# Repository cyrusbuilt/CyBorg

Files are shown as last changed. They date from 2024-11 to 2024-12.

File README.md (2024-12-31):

# CyBorg
ATX-compliant Z80-based SBC motherboard

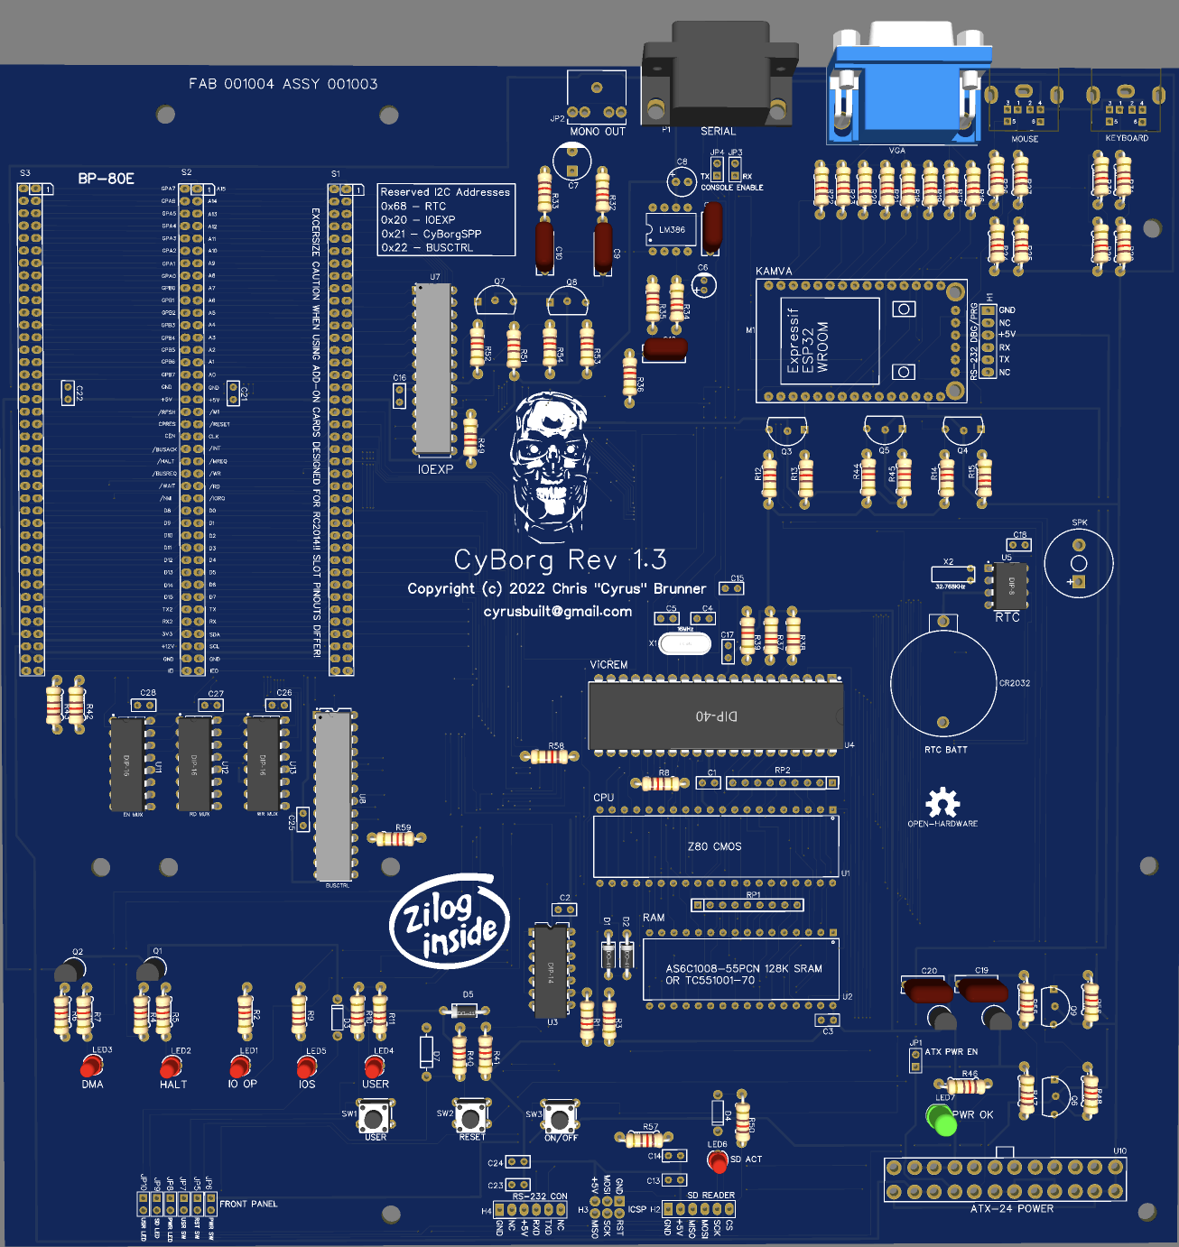
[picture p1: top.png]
CyBorg


## DISCLAIMER
This board is very much in the alpa stages and subject to design changes. This is my first SBC design and I'm learning as I go. As such this board is certainly not intended for production purposes.

## Synopsis
Being a huge fan of the retro-computing scene, and having built a few different "modern retro" computers from kits that were Z80 and Z180-based, I decided to study their schematics and try to design one myself. The design I settled on is a kind of amalgamation of the [Z80-MBC2](https://github.com/SuperFabius/Z80-MBC2) and my [CyrUX Board](https://github.com/cyrusbuilt/CyrUX) and a variation of the [RC2014 Enhanced Bus](https://smallcomputercentral.com/documentation/specification-rc2014-bus/#enhanced). CyBorg represents my first attempt at a CP/M and [Fuzix](https://github.com/EtchedPixels/FUZIX)-compatible retro computer that you can mount in a standard PC chassis.

## Features
- VGA Display (1280x768 B&W, 1024x720 4 color, 800x600 8 color, 720x520 16 color, 640x480 16 color @ 73Hz, 640x480 16 color @ 60Hz, 640x350 16 color, 512x384 64 color, and 400x300 64 color)
- PS/2 Keyboard and Mouse
- Serial Console
- Amplified Mono Audio
- Battery-backed Hardware Real-Time Clock
- Z80 CPU @ 8MHz
- 128K SRAM
- ATX 2.01-compliant
- Header for microSD card reader
- Front Panel Headers
- BP-80E Expansion Slots x3
- iLoad Intel-HEX loader firmware embedded.
- Optionally boots CP/M 2.2, CP/M 3, QP/M 2.71, Forth, BASIC, and Fuzix.

## Feature Break-Down
The features on this board are implemented using what I call "ViCREM" (formerly "Northbridge") and "KAMVA" (formerly "SouthBridge"). Both chips are responsible for different areas of the board. The Southbridge operates identically to my CyrUX board, but with ATX power management and boot sequence control added to it. The following is a breakdown of what each is and does:

## ViCREM (formerly 'Northbridge')
1) Atmel ATMEGA32A-PU
2) Specs:
	* 8-bit MCU @ 16MHz
	* 40-pin DIP package
	* 32KB Flash
	* 8KB EEPROM
	* 16KB RAM
3) Responsibilities:
	* Choreograph data between CPU, RAM, and data bus.
	* Control and provide interface for RTC (DS1307).
	* Control and provide interface for I/O expansion (via MCP23017).
	* Control onboard buzzer/speaker.
	* Communicate with Southbridge.
	* Expose OpCodes for system programming.
	* Provides system clock (4/8MHz).
	* Provides system ROM and bootstrapping.
	* RS-232 UART.

## KAMVA (formerly 'Southbridge')
1) [Adafruit Huzzah ESP32](https://www.adafruit.com/product/4172)
2) Specs:
	* 32bit dual-core Tensilica LX6 MCU @ 240MHz.
	* 520KB SRAM.
	* 802.11b/g/n HT40 Wi-Fi.
	* Dual-mode Bluetooth (classic and BLE).
	* 4MB Flash
	* PCB antenna
3) Responsibilities:
	* ATX Power management.
	* Boot sequence control.
	* [FabGL-based](https://github.com/fdivitto/FabGL) Terminal System which provides:
	* PS/2 Keyboard and Mouse input.
	* Amplified Mono Audio Output (LM386).
	* VGA Display Output.
	* Possible future networking support.

## Core
1) Zilog Z80 CMOS CPU @ 8MHz
	* Main System Processor.
2) AS6C1008-55PCN 128KB SRAM (banked 64K x 2)
	* Main System RAM.

## Expansion Bus Slots
The expansion bus slots are an unofficial variation of the RC2014 Enhanced bus I call "BP-80E" or "BP-80 Enhanced" which is kind of a misnomer given the actual pinout of the unofficial BP-80 bus definition, but seemed appropriate for my purposes (at least until I come up with a better name for it). It is pin-compatible with the RC2014 Standard and Enhanced bus slots and therefore should be compatible with existing add-on boards, but adds the following changes:
1) Pins 41 - 56 map to the I/O pins on the MCP23017 I/O expander and therefore gives us 16 shared GPIO pins (3.3V).
2) Pins 39 and 79 are additional GND.
3) Pin 78 is +12V.
4) Pin 77 is +3.3V.
5) Pins 37 and 38 are I2C SDA & SCL (respectively).
6) Pin 60 is Card Presence indicator
7) Pin 61 is Card Enable
8) /IORQ, /WR, and /RD signals are all unique to each slot.

## Jumpers and Headers
1) Header H4: RS-232 Serial from the Northbridge/Main system. This is also tied to the DB-9 Serial port next to the VGA connector.
2) Header H3: ICSP header used to program/debug the Northbridge.
3) Header H2: This is essentially an SPI bus header used to attach the SD Card Reader.
4) Header H1: RS-232 serial header that goes directly to the Southbridge and used to program/debug the Southbridge. Intended to be used with a USB-to-Serial FTDI cable.
5) Jumper JP1: (should be jumpered for normal operation) enables power to the Southbridge via the 5VSB line from the ATX power supply. Unjumper this to enable power from the FTDI cable.
6) Jumpers JP3 and JP4: (should be jumpered for normal operation) enables the Serial connection to the Southbridge.
7) JP5: Front-panel reset switch. Momentarily short to reset the system. Same as pressing RESET button.
8) JP6: Front-panel power button. Momentarily short to power system on. Short for >= 10s to power off. Same as pressing ON/OFF button.
9) JP7: Front-panel USER button. Press and hold during power on to get boot mode selection menu. Same as pressing USER button.
10) JP8: Front-panel power LED header. Same as PWR OK LED.
11) JP9: Front-panel SD card activity LED. Same as SD ACT LED.
12) JP10: Front-panel boot mode LED. Same as USER LED.

## Boot Sequence
Being an ATX-compliant board, this system uses an ATX-24 power connector intended to be used with an ATX Power Supply. The ATX power management and boot sequence works as follows: KAMVA receives it's power from the 5VSB line, which is always on as long as the ATX power supply has power (but not necessarily "running"). On power-on KAMVA enters boot stage 0, which *only* initializes the debug port and the ATX power management system, then waits for the user to press the power button.

When the user presses and releases the power button, it then drives the ATX PC_ON line LOW to turn on the ATX supply and waits for the PWR_OK line to go HIGH (as indicated by the PWR OK LED). When the PWR_OK signal is received, the Southbridge enters boot stage 1, which initializes the VGA display, PS/2 keyboard and mouse, and audio, followed by boot stage 2 which signals ViCREM to boot. At the same time ViCREM should have received power via the +5V line and entered boot stage 0, which initializes the RS-232 serial (and debug) interface and waits for the RUN signal line to go HIGH. The last step of KAMVA's boot stage 2 should drive the RUN_3V3 line high and wait (5s timeout) for ViCREM to complete bootstage 1 and start receiving serial data. When ViCREM sees the RUN signal it should enter boot stage 1 which should first announce it's firmware version to the serial port then configure the WAIT and WAIT_RES lines then check the USER button for boot mode selection. Once KAMVA sees serial data, it has completed it's own boot sequence and will continuously poll the power button for presses. If the user presses and holds the power button for >= 10s, then KAMVA will force-power down by driving the PC_ON line HIGH which will immediately drop out power from the power supply forcing the rest of the system off. KAMVA will then do a soft-reboot to re-init back to boot stage 0.

Back to ViCREM, after checking for boot mode selection and storing the flag, it enters boot stage 2 which initializes all the appropriate address and data lines on the system bus, then the logical RAM banks, system clock, and console lines, then moves to boot stage 3. Stage 3 reads the CPU speed mode, boot selection, and CP/M auto-exec flags from EEPROM, initializes the I2C interface and scans for the I/O expander, RTC, BUSCTLR and IOEXP chips, and CyBorgSPP interface then outputs boot info to serial, then moves to boot stage 4. Stage 4 tries to mount the SD card (if present) and presents the user with boot mode selection menu if the USER line was LOW at boot and then proceeds to load the selected (via menu or from EEPROM or fallback to default) boot image into RAM (either from flash or from SD card), then moves to boot stage 5. Stage 5 holds the CPU in RESET, then initializes the system clock, then flushes the serial buffer, then releases the RESET line so the CPU begins executing.

Additional detail can be found in the firware projects for [ViCREM](https://github.com/cyrusbuilt/CyBorg-Northbridge) and [KAMVA](https://github.com/cyrusbuilt/CyBorg-Southbridge).

## Project Structure
All design files are in the "schematics" folder. It contains the JSON exports for the [EasyEDA](https://easyeda.com/) schematic and PCB CAD files, the BOM in CSV format, PDFs of the schematic and PCB designs, and then in schematics/gerber are the production gerber files.

## I want one!
I have no plans to make CyBorg into a commercial product nor do I intend to sell kits. So if you want to build one, you'll need to take the gerber files and have the PCB made, then order the parts listed in the BOM and assemble it yourself. You'll need to be familiar with soldering through-hole components (I recommend an adjustable temperature soldering iron) and at least a multimeter (I often use a logic probe too)) and some wire snips to cut the legs on things like resistors and capacitors to size after you solder them. **However**, at this time, I would hold off on building one until I've finalized the design.

## Cool! I built one! Now what?
You'll need an ATX power supply (you can even use a Pico PSU). The next thing you'll want to do is flash the KAMVA (formerly known as the "Southbridge") firmware. Go see the project for that [here](https://github.com/cyrusbuilt/CyBorg-Southbridge). After you've done that, you'll need to flash the ViCREM (formerly known as "Northbridge") firmware. Go see the project for that [here](https://github.com/cyrusbuilt/CyBorg-Northbridge).

## Possible Revision Changes
1) Add fan headers
2) Change expansion bus slots to different connector type.

## Sponsorship/Special Thanks
A big special thanks to [PCBWay](https://www.pcbway.com) for their sponsorship on this project! It can't be stated enough the quality of their boards and their service. I've been using PCBWay to produce my boards for years now and I've always been really impressed. Fast shipping, fast service, reasonable cost, and the quality has always been stellar. Their pre-production team has even caught mistakes I didn't notice before sending my designs in. The ordering process is simple: just upload a zip file of your gerbers (their site even renders a preview of what the board will look like!) and then you can tweak parameters if needed (including color) and quantity, pick your shipping method, and that's it! They've even produced a series of videos about the whole process you can view [here](https://www.pcbway.com/pcb-service.html?step=1#miao1).

Just look at this beauty! (I'm a huge fan of their black PCBs)
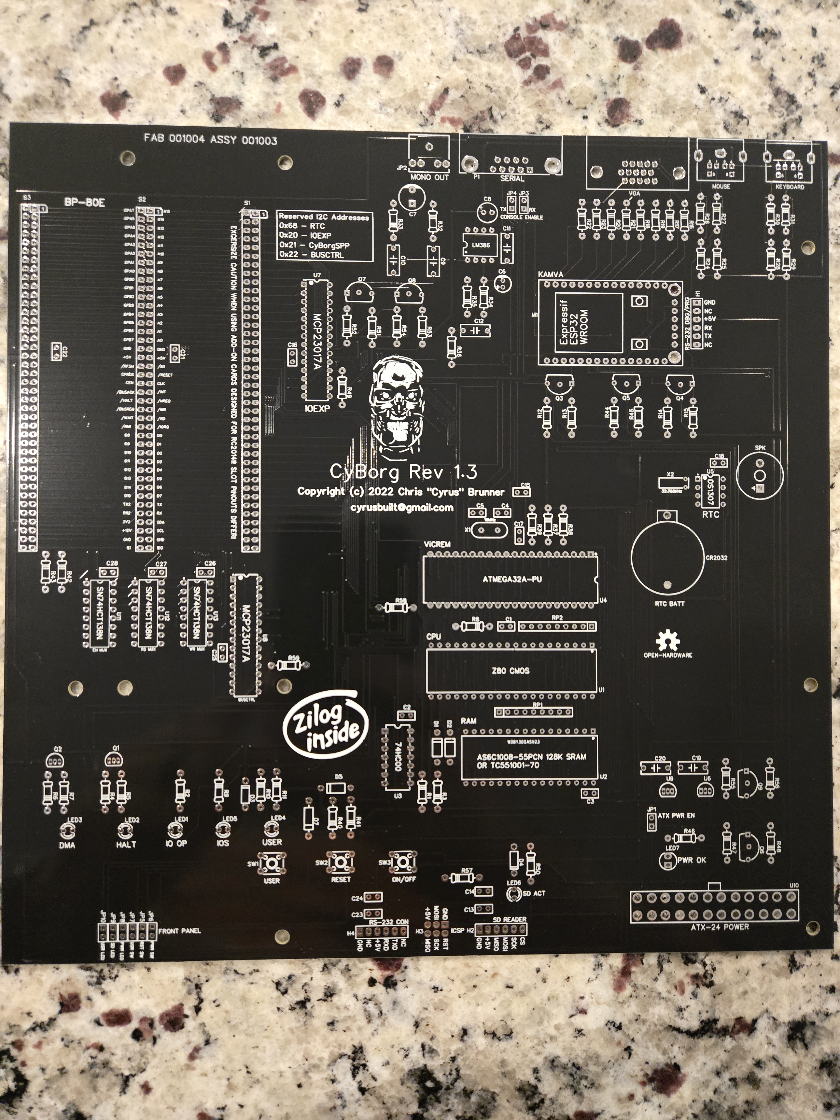
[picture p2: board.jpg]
CyBorg_Board


## Credits
- CyBorg's core is derived from the works of "Just4Fun" a.k.a "SuperFabius" ([https://github.com/SuperFabius](https://github.com/SuperFabius)) (parts of the hardware design and IOS firmware code).
- Southbridge firmware implements the FabGL library and is essentially a modified version of the AnsiTerminal example by Fabrizio Di Vittorio ([http://www.fabglib.org/index.html](http://www.fabglib.org/index.html))
- Northbridge firmware implements the PetitFS library by ChaN ([http://elm-chan.org/fsw/ff/00index_p.html](http://elm-chan.org/fsw/ff/00index_p.html))
- Southbridge firmware implements the ButtonEvent library by Renato Ferriera ([https://github.com/renatoferreirarenatoferreira/ebl-arduino/tree/master/ButtonEvent](https://github.com/renatoferreirarenatoferreira/ebl-arduino/tree/master/ButtonEvent))
- ViCREM (Northbridge) firmware uses [MightyCore](https://github.com/MCUdude/MightyCore) bootloader by [MCUDude](https://github.com/MCUdude)

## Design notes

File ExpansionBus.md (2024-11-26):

# BP-80E Expansion Bus

CyBorg uses a custom Expansion Bus used for add-on cards called "BP-80 Enhanced" (aka. "BP-80E"). This bus specification is essentially a variation of the [Official RC2014 Enhanced Bus Specification](https://smallcomputercentral.com/documentation/specification-rc2014-bus/#enhanced) with the following changes:

1) Row 2 Pins 41 - 56 are used by the 16 GPIOS provided by the MCP23017 I/O expander chip located next to the first bus connector (these pins were orginally unused).
2) Row 1 and Row 2 pins 37 - 40 were originally specified for USER functions (which could be anything), which I've assigned to extra grounds, power pins with additional voltages (+3.3V and +12V) and interrupt cascade.
3) Row 2 Pins 60 & 61 are used for Card Presence and Card Enable (respectively).

With the exception of the above pin assignment changes, all other pin definitions remain the same and as such, *should be* compatible with official [RC2014](https://rc2014.co.uk/) add-on cards and cards designated as being "Designed for RC2014" with the caveat of any card that specifically uses any of the above pins for other purposes would, of course, not be compatible and could therefore potentially cause damage to both this board and any board you plug into intended for use in RC2014-compatible systems. **USE WITH CAUTION**.

# LEGAL DISCLAIMER
I am not liable for any damage to any device you interface with this board, particularly if you ignore the above information. While I did adopt a *similar* expansion bus, they are NOT the same and should not be treated as such. This board should not be considered to be a RC2014-compatible system. They are fundamentally different! I only offer the above info because I have indeed tested at least one add-on board designated as being "Designed for RC2014" without issue, but you should excersize caution and if you don't know for sure, don't try it!

# Expansion Bus Pinout

The following table describes the pin definitions:

| Row  | Pin # | Signal | Description |
| :--- | :---  | :--- | :--- |
| 1 (R)| 1 | A15 | Address bit 15 |
| 1 (R)| 2 | A14 | Address bit 14 |
| 1 (R)| 3 | A13 | Address bit 13 |
| 1 (R)| 4 | A12 | Address bit 12 |
| 1 (R)| 5 | A11 | Address bit 11 |
| 1 (R)| 6 | A10 | Address bit 10 |
| 1 (R)| 7 | A9 | Address bit 9 |
| 1 (R)| 8 | A8 | Address bit 8 |
| 1 (R)| 9 | A7 | Address bit 7 |
| 1 (R)| 10 | A6 | Address bit 6 |
| 1 (R)| 11 | A5 | Address bit 5 |
| 1 (R)| 12 | A4 | Address bit 4 |
| 1 (R)| 13 | A3 | Address bit 3 |
| 1 (R)| 14 | A2 | Address bit 2 |
| 1 (R)| 15 | A1 | Address bit 1 |
| 1 (R)| 16 | A0 | Address bit 0 |
| 1 (R)| 17 | GND | Ground |
| 1 (R)| 18 | +5V | +5V DC |
| 1 (R)| 19 | /M1 | Opcode fetch cycle |
| 1 (R)| 20 | /RESET | Northbridge/CPU reset |
| 1 (R)| 21 | CLK | CPU Clock |
| 1 (R)| 22 | /INT | Maskable Interrupt |
| 1 (R)| 23 | /MREQ  | Memory Request |
| 1 (R)| 24 | /WR | Write data**** |
| 1 (R)| 25 | /RD | Read data**** |
| 1 (R)| 26 | /IORQ  | I/O Request**** |
| 1 (R)| 27 | D0 | Data bit 0 |
| 1 (R)| 28 | D1 | Data bit 1 |
| 1 (R)| 29 | D2 | Data bit 2 |
| 1 (R)| 30 | D3 | Data bit 3 |
| 1 (R)| 31 | D4 | Data bit 4 |
| 1 (R)| 32 | D5 | Data bit 5 |
| 1 (R)| 33 | D6 | Data bit 6 |
| 1 (R)| 34 | D7 | Data bit 7 |
| 1 (R)| 35 | TX | Serial Transmit (UART) |
| 1 (R)| 36 | RX | Serial Recieve (UART) |
| 1 (R)| 37 | SDA | I2C Serial Data |
| 1 (R)| 38 | SCL | I2C Serial Clock |
| 1 (R)| 39 | GND | Ground |
| 1 (R)| 40 | IEO | Interrupt cascade (out) |
| 2 (L)| 41 | GPA7 | IOEX Port A bit 7* |
| 2 (L)| 42 | GPA6 | IOEX Port A bit 6* |
| 2 (L)| 43 | GPA5 | IOEX Port A bit 5* |
| 2 (L)| 44 | GPA4 | IOEX Port A bit 4* |
| 2 (L)| 45 | GPA3 | IOEX Port A bit 3* |
| 2 (L)| 46 | GPA2 | IOEX Port A bit 2* |
| 2 (L)| 47 | GPA1 | IOEX Port A bit 1* |
| 2 (L)| 48 | GPA0 | IOEX Port A bit 0* |
| 2 (L)| 49 | GPB0 | IOEX Port B bit 0* |
| 2 (L)| 50 | GPB1 | IOEX Port B bit 1* |
| 2 (L)| 51 | GPB2 | IOEX Port B bit 2* |
| 2 (L)| 52 | GPB3 | IOEX Port B bit 3* |
| 2 (L)| 53 | GPB4 | IOEX Port B bit 4* |
| 2 (L)| 54 | GPB5 | IOEX Port B bit 5* |
| 2 (L)| 55 | GPB6 | IOEX Port B bit 6* |
| 2 (L)| 56 | GPB7 | IOEX Port B bit 7* |
| 2 (L)| 57 | GND | Ground |
| 2 (L)| 58 | +5V | +5V DC |
| 2 (L)| 59 | /RFSH  | Refresh |
| 2 (L)| 60 | CPRES  | Card Presence indicator* |
| 2 (L)| 61 | CEN | Card Enable* |
| 2 (L)| 62 | /BUSACK| Bus acknowledge |
| 2 (L)| 63 | /HALT  | Halt/pause execution |
| 2 (L)| 64 | /BUSREQ| Bus request |
| 2 (L)| 65 | /WAIT  | Enter wait state |
| 2 (L)| 66 | /NMI | Non-Maskable Interrupt |
| 2 (L)| 67 | D8 | Data bit 8** |
| 2 (L)| 68 | D9 | Data bit 9** |
| 2 (L)| 69 | D10 | Data bit 10** |
| 2 (L)| 70 | D11 | Data bit 11** |
| 2 (L)| 71 | D12 | Data bit 12** |
| 2 (L)| 72 | D13 | Data bit 13** |
| 2 (L)| 73 | D14 | Data bit 14** |
| 2 (L)| 74 | D15 | Data bit 15** |
| 2 (L)| 75 | TX2 | Serial Transmit 2*** |
| 2 (L)| 76 | RX2 | Serial Receive 2*** |
| 2 (L)| 77 | 3V3 | +3.3V DC |
| 2 (L)| 78 | +12V | +12V DC |
| 2 (L)| 79 | GND | Ground |
| 2 (L)| 80 | IEI | Interrupt cascade (in) |

\* - Denotes signal level is 3.3V. All other signals are at a 5V level.

\** - Denotes data bus signal is present on expansion bus *ONLY* and does not connect to the CPU's data bus.

\*** - Denotes serial signals present on the expansion bus *ONLY* and does not connect to any UART present on  ViCREM or KAMVA.

\**** - Denotes signal is unique to the slot, meaning: it's individually controlled by the associated
mux chip for each signal and assigned to the specific slot.

\/ - Signal prefix denotes a signal that is active low.

See the [Z80 CPU User Manual](https://www.zilog.com/docs/z80/um0080.pdf) for documentation on the Z80-specific signals above.

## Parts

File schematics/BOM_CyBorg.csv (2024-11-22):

ID | Name | Designator | Footprint | Quantity | Manufacturer Part | Manufacturer | Supplier | Supplier Part | Price
1 | 100nF | C1,C2,C3,C16,C21,C22,C25,C26,C27,C28 | CAP-RAD-2.54MM | 10
2 | 22pF | C4,C5 | CAP-RAD-2.54MM | 2
3 | 10uF | C6 | ELECTROLYTIC CAPACITOR | 1 | electrolytic capacitor 10UF 50V high frequency | ValuePro | LCSC | C78759 | 0.014
4 | 220uF | C7 | 220UF ELECTROLYTIC | 1 | Aluminum electrolytic capacitors47uF 63V 20% High frequency green gold | ValuePro |  | C60712 | 0.023
5 | 100uF | C8 | ELECTROLYTIC CAPACITOR 100UF | 1
6 | 47nF | C9 | CAP-TH_L8.8-W3.6-P7.30-D0.5 | 1 | 0.1uF/250V | null | LCSC | C9900015263
7 | 2.2nF | C10 | CAP-TH_L8.8-W3.6-P7.30-D0.5 | 1 | 0.1uF/250V | null | LCSC | C9900015263
8 | 100nF | C11 | CAP-TH_L8.8-W3.6-P7.30-D0.5 | 1 | 0.1uF/250V | null | LCSC | C9900015263
9 | 0.1uF | C12 | CAP-TH_L8.8-W3.6-P7.30-D0.5 | 1 | 0.1uF/250V | null | LCSC | C9900015263
10 | 0.1uF | C13,C15,C17,C18,C23 | CAP-RAD-2.54MM | 5
11 | 100uF | C14,C24 | CAP-RAD-2.54MM | 2
12 | 1nF | C19,C20 | CAP-TH_L8.8-W3.6-P7.30-D0.5 | 2 | 0.1uF/250V | null | LCSC | C9900015263
13 | BATT-CR2032 | CR2032 | BATT-CR2032 | 1
14 | 1N5817_C698892 | D1,D2,D5 | DO-41_BD2.4-L4.7-P8.70-D0.9-RD | 3 | 1N5817 | YANGJIE(扬杰) | LCSC | C698892 | 0.036
15 | 1N4148 | D3,D4 | 1N4148 | 2
16 | DIODE | D7 | DIODE-1N4001 | 1
17 | RS-232 | H1,H4 | HEADER-1X6-2.54MM | 2
18 | SD_READER | H2 | HEADER-1X6-2.54MM | 1
19 | ICSP | H3 | ICSP - 1 | 1
20 | ATX_PWR_EN | JP1 | HDR1X2 | 1
21 | AUDIO-JACK PTH | JP2 | AUDIO-JACK | 1
22 | RX_CON_EN | JP3 | HDR1X2 | 1
23 | TX_CON_EN | JP4 | HDR1X2 | 1
24 | RESET HDR | JP5 | HDR1X2 | 1
25 | PWR_BTN_HDR | JP6 | HDR1X2 | 1
26 | USER HDR | JP7 | HDR1X2 | 1
27 | PWR_OK | JP8 | HDR1X2 | 1
28 | SD_ACT | JP9 | HDR1X2 | 1
29 | USER_IND | JP10 | HDR1X2 | 1
30 | PS/2 Connector | KEYBOARD,MOUSE | PS2_PORT | 2
31 | IO_OP | LED1 | LED-TH_BD3.0-P2.54-FD | 1 | 204-10SURD/S530-A3 | EVERLIGHT(亿光) | LCSC | C99772 | 0.027
32 | HALT | LED2 | LED-TH_BD3.0-P2.54-FD | 1 | 204-10SURD/S530-A3 | EVERLIGHT(亿光) | LCSC | C99772 | 0.027
33 | DMA | LED3 | LED-TH_BD3.0-P2.54-FD | 1 | 204-10SURD/S530-A3 | EVERLIGHT(亿光) | LCSC | C99772 | 0.027
34 | USER | LED4 | LED-TH_BD3.0-P2.54-FD | 1 | 204-10SURD/S530-A3 | EVERLIGHT(亿光) | LCSC | C99772 | 0.027
35 | IOS | LED5 | LED-TH_BD3.0-P2.54-FD | 1 | 204-10SURD/S530-A3 | EVERLIGHT(亿光) | LCSC | C99772 | 0.027
36 | SD_ACT | LED6 | LED-TH_BD3.0-P2.54-FD | 1 | 204-10SURD/S530-A3 | EVERLIGHT(亿光) | LCSC | C99772 | 0.027
37 | LED 5MM GREEN | LED7 | LED 5MM GREEN | 1
38 | LM386 | LM386 | LM386 | 1 | LM386N-1/NOPB | LM386N-1/NOPB | Digi-Key
39 | HUZZAH-ESP32 | M1 | HUZZAH-ESP32 | 1
40 | RS232 DB-9 | P1 | DB9-TH_DB9-H-F_C2888345 | 1 | RS232DB99pin90度母座 | null | LCSC | C9900003665
41 | 2N2907 | Q1,Q2 | TO-92-3_L5.1-W4.1-P1.27-L | 2 | 2N2907A | ST(先科) | LCSC | C118537 | 0.023
42 | 2N7000 | Q3,Q4,Q5,Q6,Q7,Q8,Q9 | 2N7000 TO-92 B | 7
43 | 10K | R1,R4,R6,R8 | PKG-0.25W RESISTOR | 4 | MCF 0.25W 150R | MULTICOMP | Element14 | 9339175
44 | 1K | R2 | PKG-0.25W RESISTOR | 1 | MCF 0.25W 1K | MULTICOMP | Element14 | 9339175
45 | 1K2 | R3 | PKG-0.25W RESISTOR | 1 | MCF 0.25W 150R | MULTICOMP | Element14 | 9339175
46 | 680 | R5,R9 | PKG-0.25W RESISTOR | 2 | MCF 0.25W 150R | MULTICOMP | Element14 | 9339175
47 | 1K | R7 | PKG-0.25W RESISTOR | 1 | MCF 0.25W 150R | MULTICOMP | Element14 | 9339175
48 | 390 | R10,R11,R18,R20,R22 | PKG-0.25W RESISTOR | 5 | MCF 0.25W 150R | MULTICOMP | Element14 | 9339175
49 | 10k | R12,R13,R14,R15,R33,R34,R37,R38,R39,R41,R44,R45,R47,R48,R51,R52,R53,R54,R55,R56,R57 | PKG-0.25W RESISTOR | 21 | MCF 0.25W 150R | MULTICOMP | Element14 | 9339175
50 | 220 | R16,R17,R46 | PKG-0.25W RESISTOR | 3 | MCF 0.25W 150R | MULTICOMP | Element14 | 9339175
51 | 820 | R19,R21,R23 | PKG-0.25W RESISTOR | 3 | MCF 0.25W 150R | MULTICOMP | Element14 | 9339175
52 | 2k | R24,R25,R28,R29 | PKG-0.25W RESISTOR | 4 | MCF 0.25W 150R | MULTICOMP | Element14 | 9339175
53 | 120 | R26,R27,R30,R31 | PKG-0.25W RESISTOR | 4 | MCF 0.25W 150R | MULTICOMP | Element14 | 9339175
54 | 10 | R32 | PKG-0.25W RESISTOR | 1 | MCF 0.25W 150R | MULTICOMP | Element14 | 9339175
55 | 150 | R35 | PKG-0.25W RESISTOR | 1 | MCF 0.25W 150R | MULTICOMP | Element14 | 9339175
56 | 270 | R36 | PKG-0.25W RESISTOR | 1 | MCF 0.25W 150R | MULTICOMP | Element14 | 9339175
57 | 1k | R40 | PKG-0.25W RESISTOR | 1 | MCF 0.25W 150R | MULTICOMP | Element14 | 9339175
58 | 4k7 | R42,R43,R49,R59 | PKG-0.25W RESISTOR | 4 | MCF 0.25W 150R | MULTICOMP | Element14 | 9339175
59 | 330 | R50 | PKG-0.25W RESISTOR | 1 | MCF 0.25W 330R | MULTICOMP | Element14 | 9339175
60 | 39 | R58 | PKG-0.25W RESISTOR | 1 | MCF 0.25W 330R | MULTICOMP | Element14 | 9339175
61 | Resistor SIL x8 | RP1,RP2 | SIL-9 | 2
62 | BP-80E Card Socket | S1,S2,S3 | RC2014-HDR-2X40-S-F-R-2.54MM | 3
63 | BUZZER Ekulit RMP-14SP | SPK | BUZZER-R14-2P-7.6PITCH | 1 |  | Ekulit |  | RMP-14SP
64 | USER | SW1 | KEY-TH_4P-L6.0-W6.0-P4.50-LS6.5 | 1 | K2-1102DP-E4SW-04 | 韩国韩荣 | LCSC | C136684 | 0.04
65 | RESET | SW2 | KEY-TH_4P-L6.0-W6.0-P4.50-LS6.5 | 1 | K2-1102DP-E4SW-04 | 韩国韩荣 | LCSC | C136684 | 0.04
66 | PWR_ON_OFF | SW3 | KEY-TH_4P-L6.0-W6.0-P4.50-LS6.5 | 1 | K2-1102DP-E4SW-04 | 韩国韩荣 | LCSC | C136684 | 0.04
67 | Z80 | U1 | DIP40 | 1 | Z84C0008PEG
68 | AS6C1008-55PCN | U2 | DIP32 | 1 | AS6C1008-55PCN
69 | 74HC00N | U3 | DIP-14_L19.0-W7.0-P2.54-LS7.6-BL | 1 | 74HC00N | HTC Korea TAEJIN Tech | LCSC | C596352 | 0.659
70 | ATMEGA32A-PU | U4 | DIP-40_L52.3-W13.9-P2.54-LS15.2-BL | 1 | ATMEGA32A-PU | MICROCHIP | LCSC | C12703 | 5.22
71 | DS1307N | U5 | DIP-8_L9.8-W6.6-P2.54-LS7.6-BL | 1 | DS1307N | HGSEMI | LCSC | C434596 | 0.406
72 | DS1233-5+ | U6,U9 | TO-92-3_L4.9-W3.7-P1.27-L | 2 | DS1233-10+ | Maxim Integrated | LCSC | C474045 | 1.24
73 | MCP23017-E/SP | U7,U8 | DIP-28_L35.0-W6.5-P2.54-LS7.6-BL | 2 | MCP23017-E/SP | Microchip Tech | LCSC | C647352 | 1.999
74 | FR_ATX24 | U10 | FR_ATX24 | 1 | ATX-24
75 | SN74HCT138N | U11,U12,U13 | DIP-16_L19.2-W6.6-P2.54-LS7.6-BL | 3 | SN74HCT138N | TI(德州仪器) | LCSC | C67461 | 0.515
76 | VGA-001 | VGA | D-SUB-TH_VGA-002 | 1 | VGA-002 | BOOMELE(博穆精密) | LCSC | C138387 | 0.21
77 | 16MHz | X1 | OSC-TH_L10.0-W4.5-P5.00 | 1 | X49SD16MSD2SC | YXC(扬兴晶振) | LCSC | C16212 | 0.083
78 | Xtal 32.768KHz | X2 | XTAL 32.768KHZ | 1

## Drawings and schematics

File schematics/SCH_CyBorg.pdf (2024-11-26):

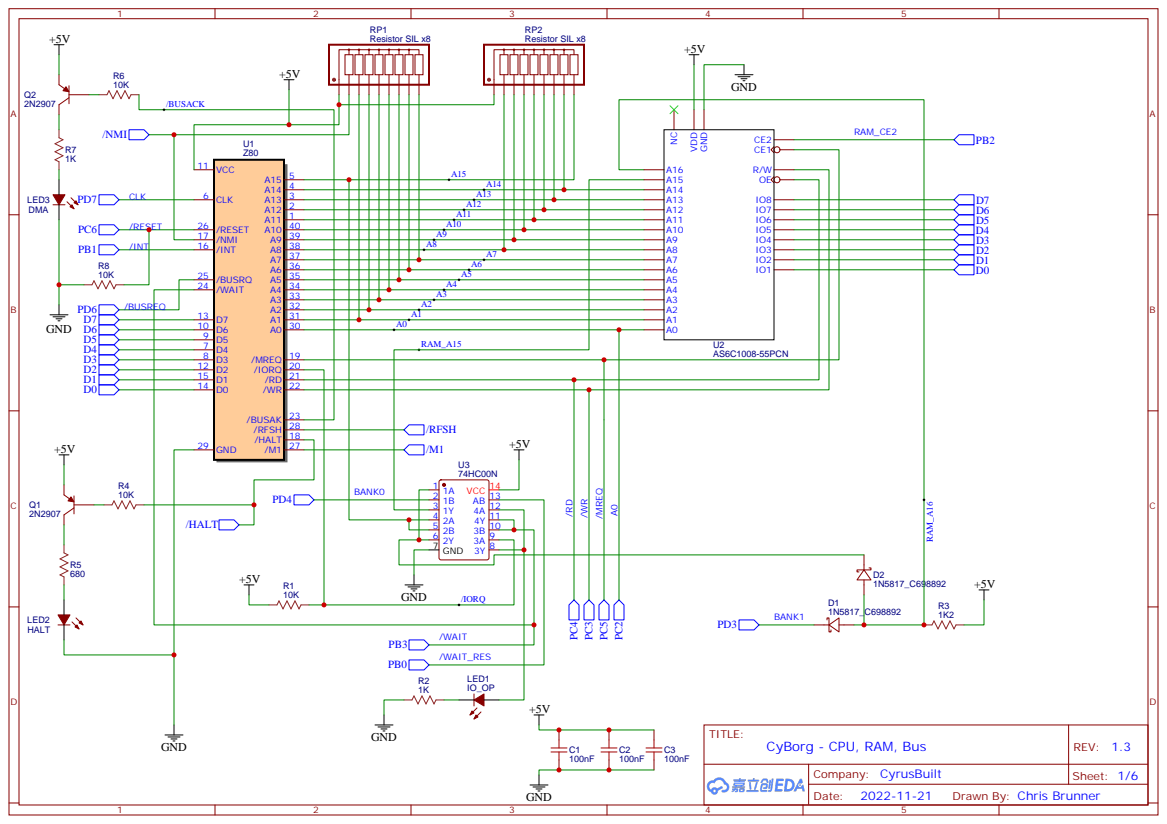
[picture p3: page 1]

Drawn By: Chris Brunner

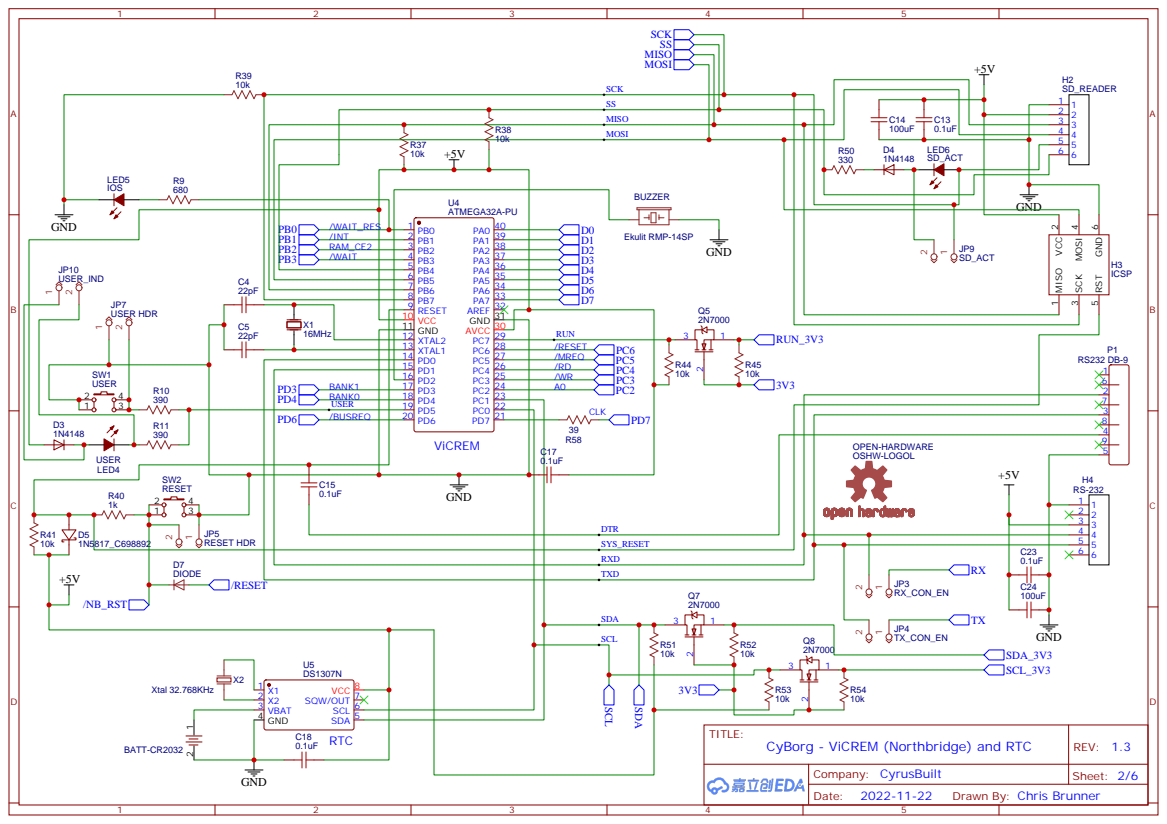
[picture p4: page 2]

MISO
MOSI

## MCU & SERIAL COMM. SECTION

## KAMVA

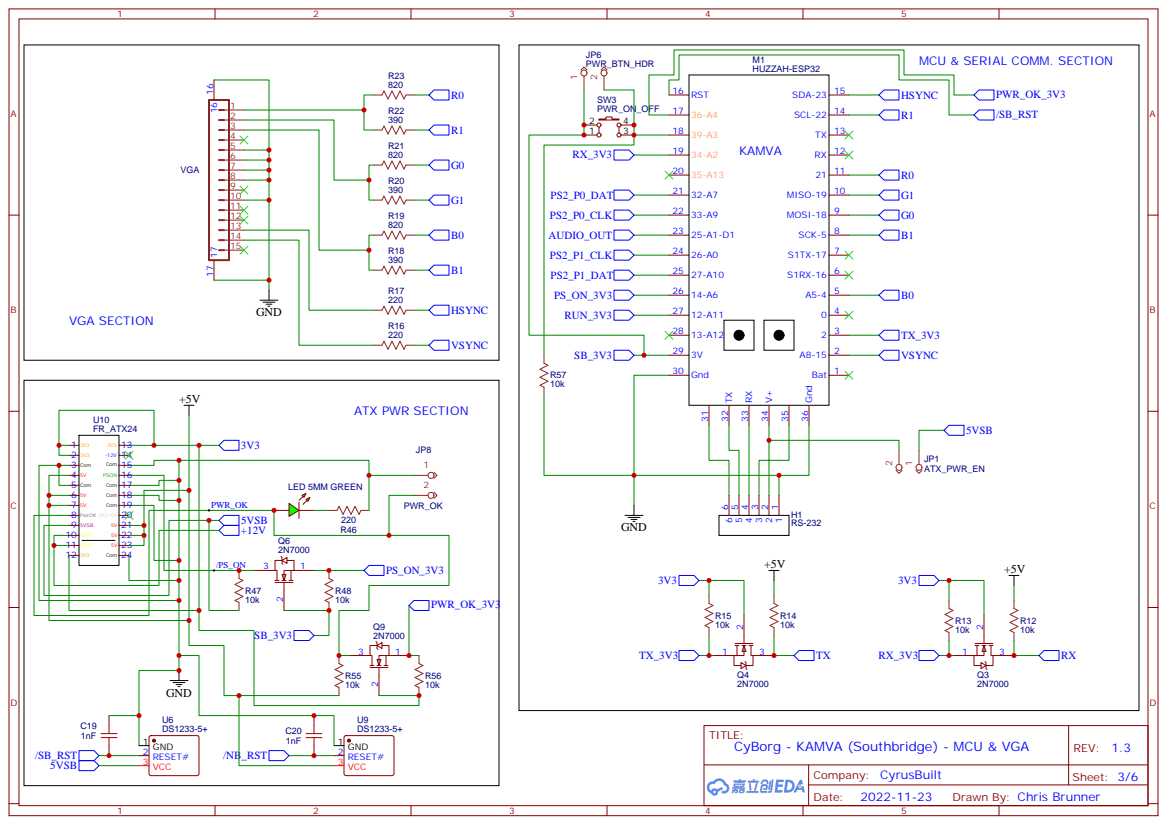
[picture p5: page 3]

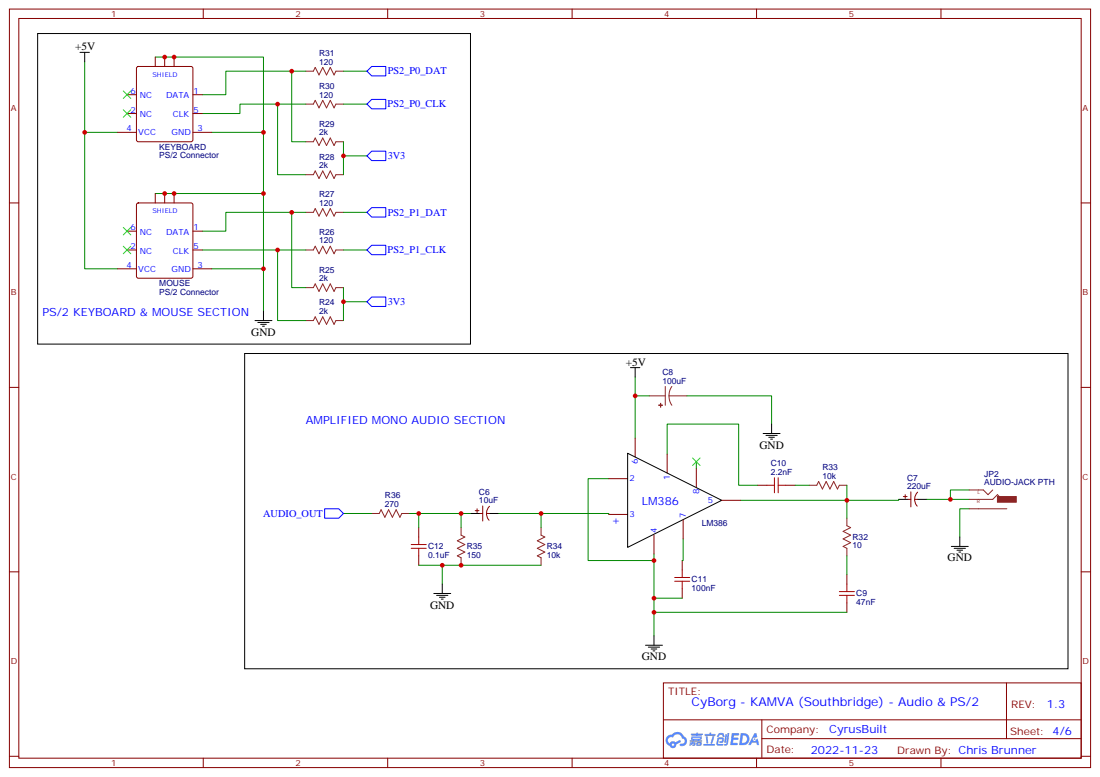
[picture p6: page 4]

AMPLIFIED MONO AUDIO SECTION

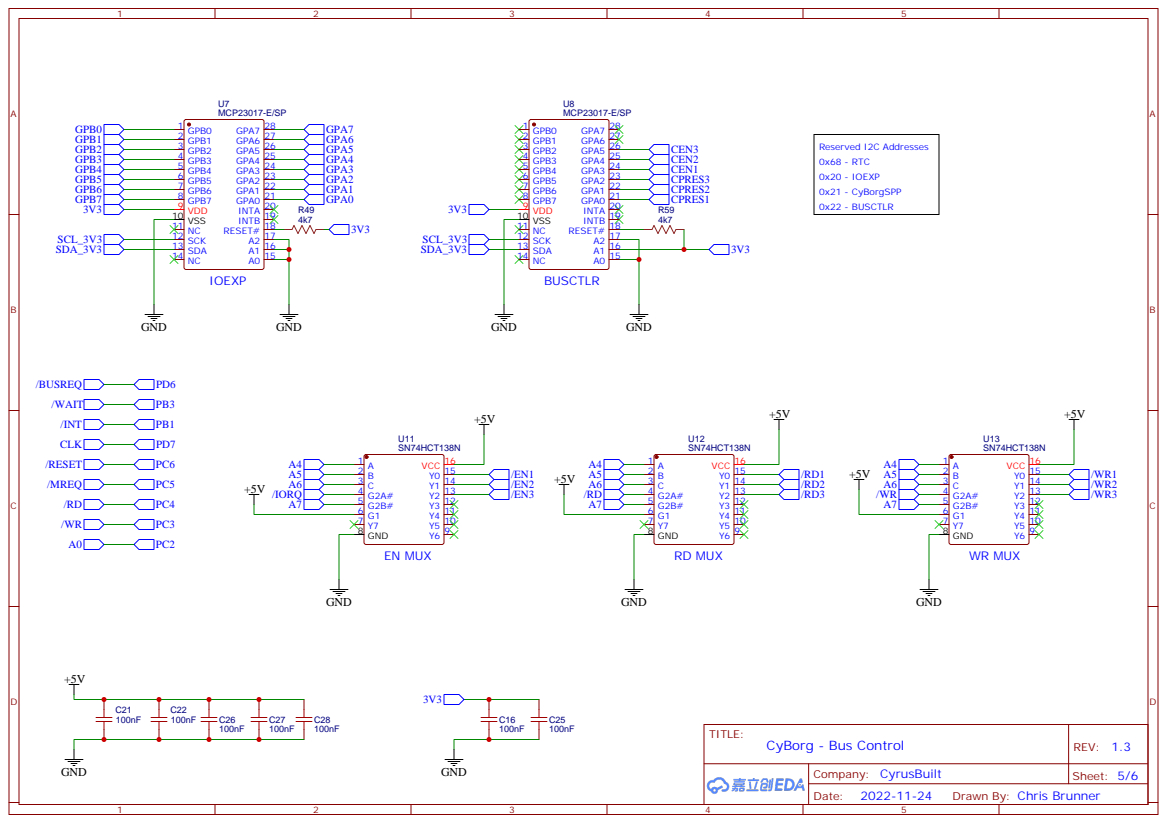
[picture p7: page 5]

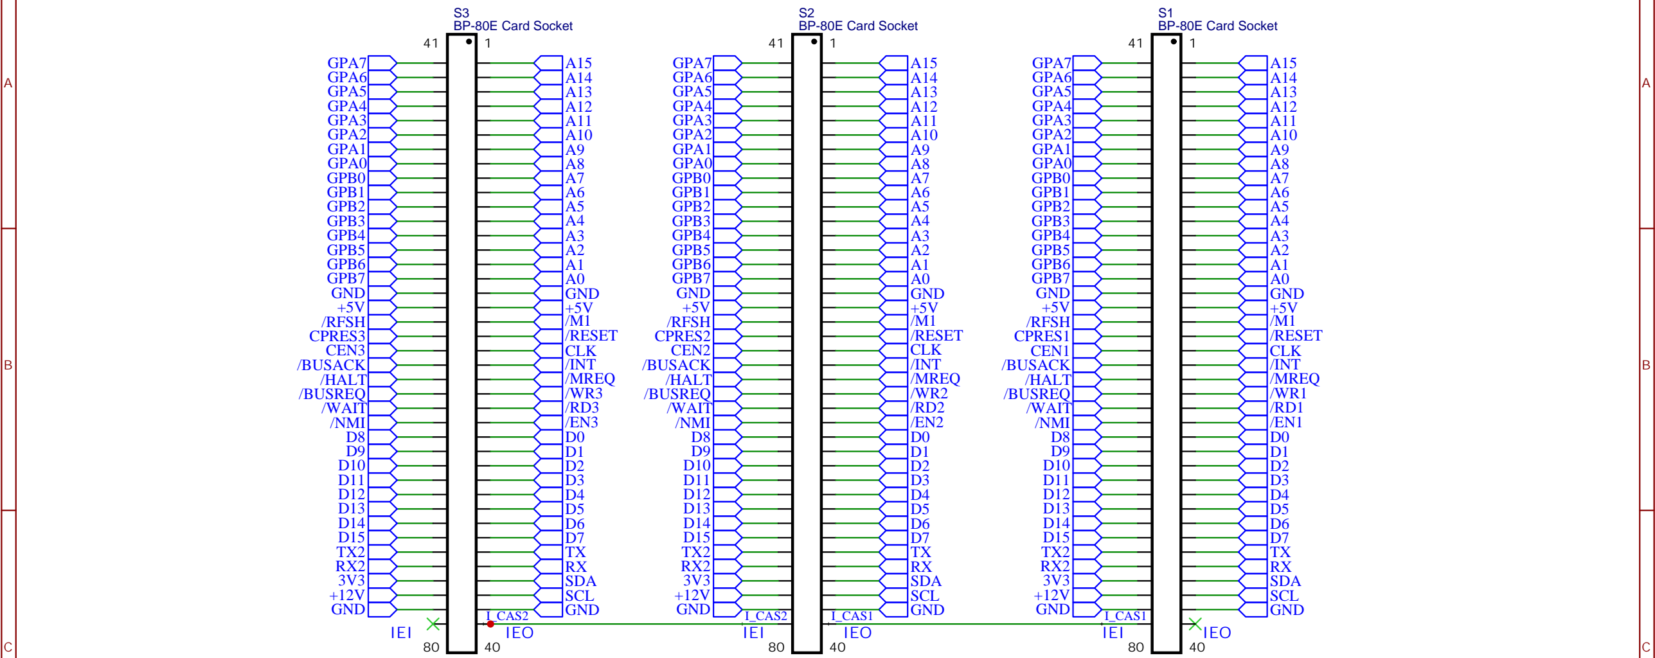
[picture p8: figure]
CPRES3; CPRES2; CPRES1; IEI; IEO; I_CAS2; I_CAS1; BP-80E Card Socket; GPA7 GPA6 GPA5 GPA4 GPA3 GPA2 GPA1 GPA0 GPB0 GPB1 GPB2 GPB3 GPB4 GPB5 GPB6 GPB7; GND; /RFSH; /BUSACK /HALT /BUSREQ /WAIT /NMI; /M1 /RESET CLK; /INT /MREQ /WR3 /RD3 /EN3 D0 D1 D2 D3 D4 D5 D6 D7 TX RX; SDA SCL; /INT /MREQ /WR2 /RD2 /EN2 D0 D1 D2 D3 D4 D5 D6 D7 TX RX; SCL; SDA; /MREQ; /INT; CLK; /RESET; /NMI; /WAIT; /BUSREQ; /HALT; /BUSACK; GPB7; GPB6; GPB5; GPB4; GPB3; GPB2; GPB1; GPB0; GPA0; GPA1; GPA2; GPA3; GPA4; GPA5; GPA6; GPA7; CEN3; CEN2; CEN1

D | D

### TITLE:

CyBorg - Expansion Bus | REV: 1.3
Date: | 2024-11-05

## BP-80E is an unofficial variant of the RC2014 bus. BP-80E is essentially a modification of the RC80 bus which is also an unofficial RC2014 bus variant. The major differences

are: A16-A23 are instead assigned to GPB0-7, n41-n48 are instead assigned to GPA0-7,

pins 60 & 61 are used for detection, and USER pins are assigned to extra power pins and(much like RC80) I2C bus, and interrupt cascade. This creates the potential danger when using cards designed for RC2014 and the like: If the add-on doesn't expect power on the USER pins (for example), you could fry the

board or worse. Any add-on card that just uses the traditional power pins, address bus,

## data bus, and control signals should work fine and, of course, any boards specifically designed for the BP-80E bus should also be fine. In a future version I may change this

to an entirely different slot type to avoid potential problems.

4k7

R43

4k7

R42
SDA

SCL

+5V

## I2C Bus Term On Slot 3

### Use caution when using add-on cards designed for RC2014!!

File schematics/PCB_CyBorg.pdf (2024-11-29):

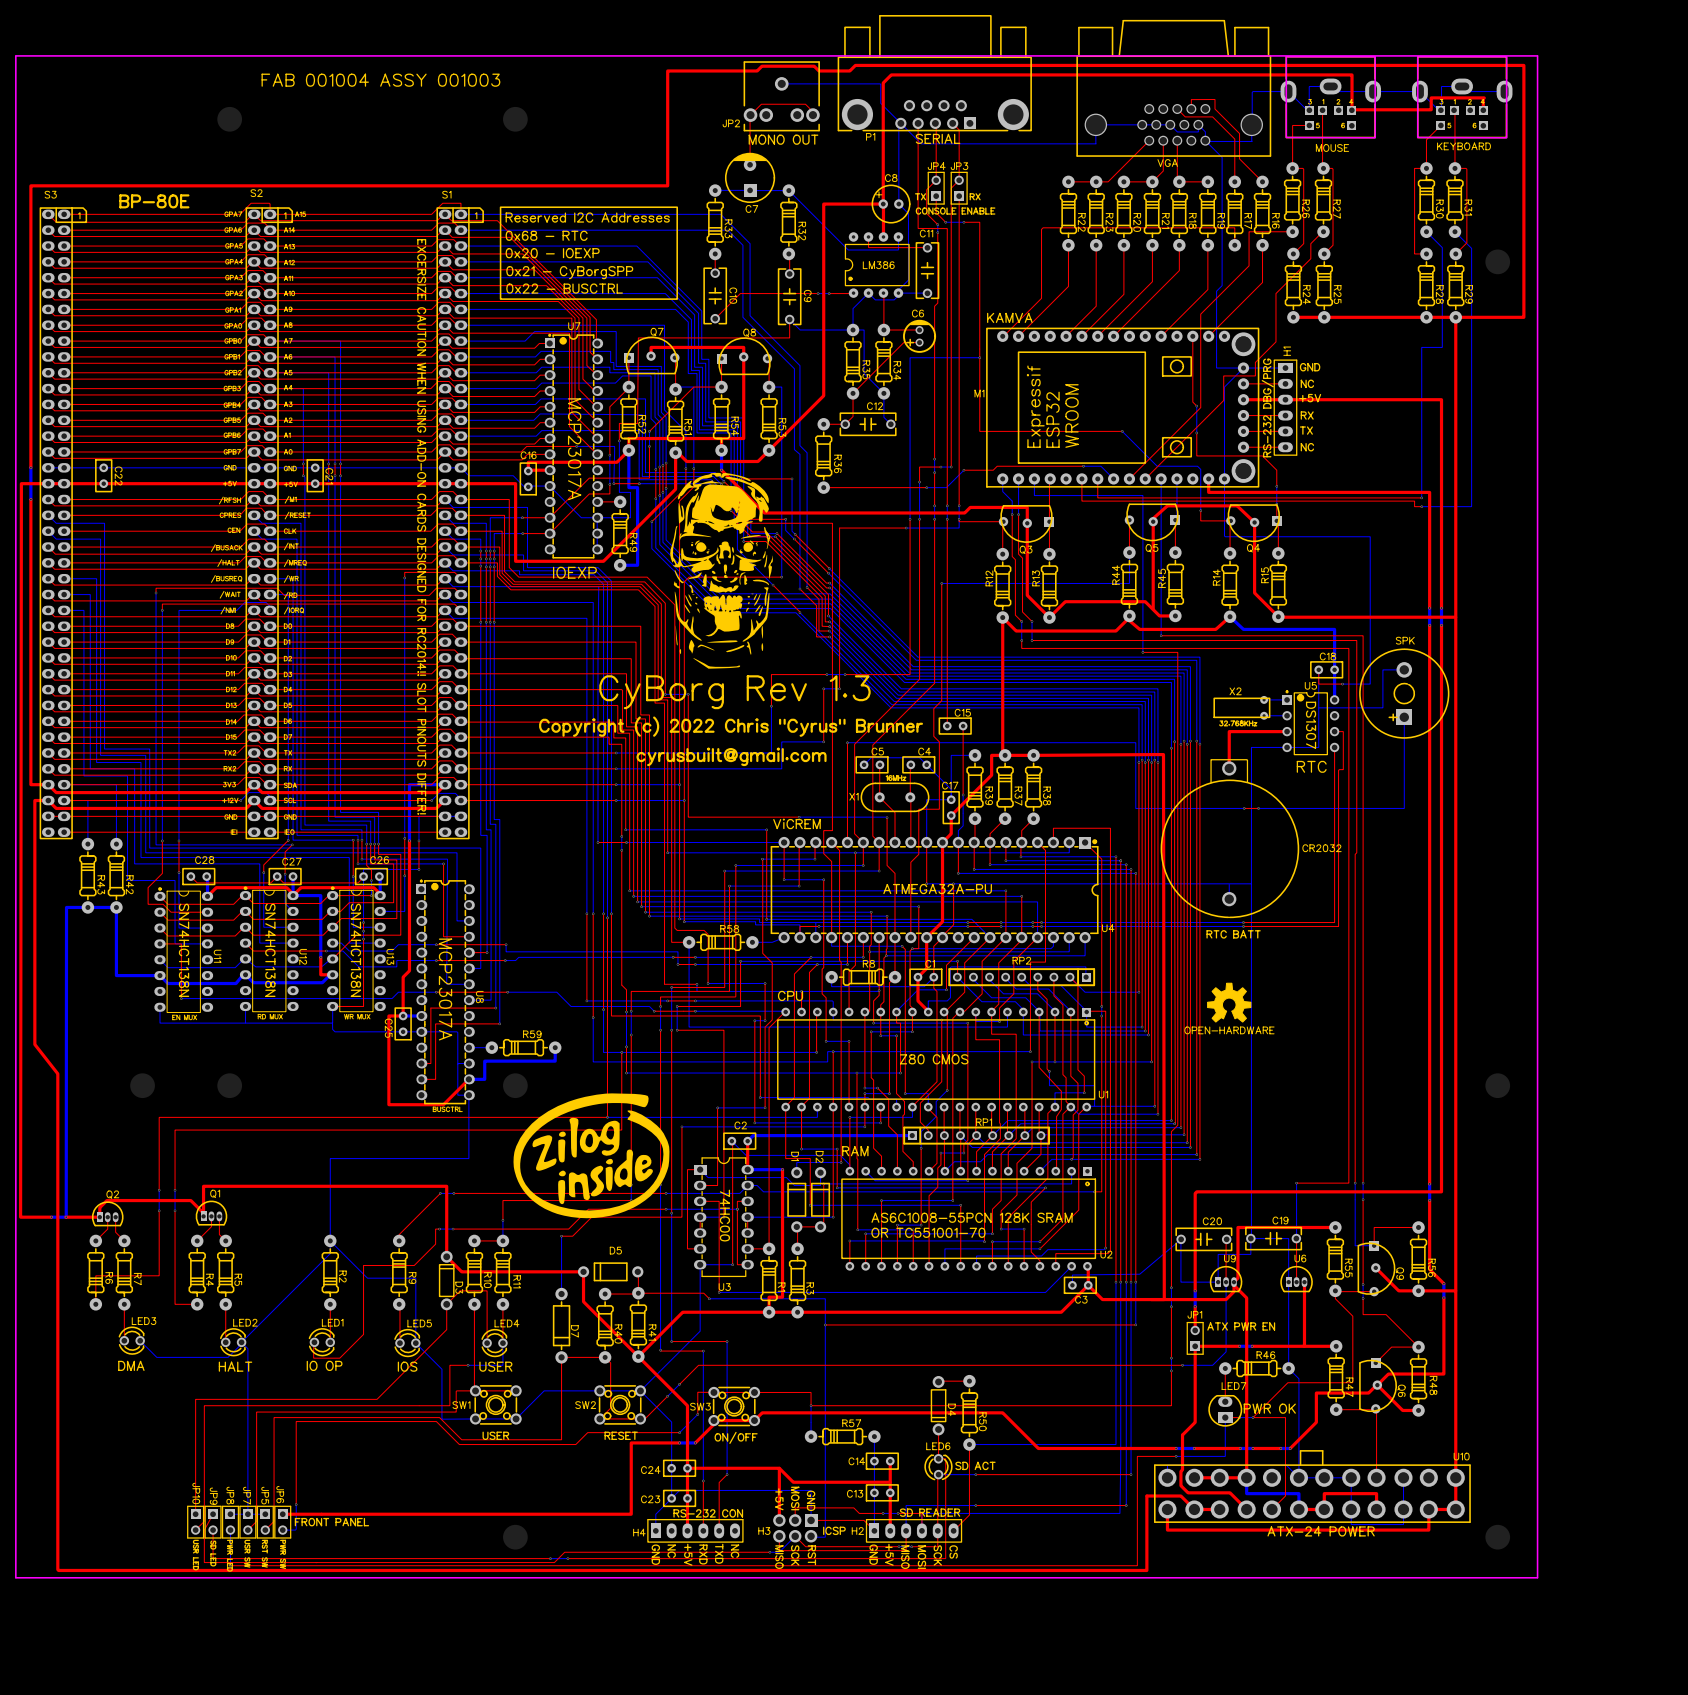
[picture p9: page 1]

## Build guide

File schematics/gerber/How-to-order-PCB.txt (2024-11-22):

How to Order PCB

Please refer to:
https://docs.easyeda.com/en/PCB/Order-PCB

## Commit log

2022-12-20 Initial release
    [BOM_CyBorg.csv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]
2022-12-20 Adding board render and proj struct docs
2023-01-04 Design fixes around southbridge
    [BOM_CyBorg.csv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]
2023-01-30 Swap RX/TX lines between NB & SB.
    [Drill_NPTH_Through.DRL, Drill_PTH_Through.DRL, Drill_PTH_Through_Via.DRL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]
2023-03-14 Missing decoupling cap on DS1307. Doc fixes
    [BOM_CyBorg.csv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]
2023-03-31 Power supervisors. ATX24. Exp bus specs
    [BOM_CyBorg.csv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]
2023-03-31 Update board rendering
2024-11-22 Adding bus ctrl and pseudo-PnP support. Lots of design fixes.
    [BOM_CyBorg.csv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]
2024-11-26 Lots of design fixes and doc updates
    [Drill_NPTH_Through.DRL, Drill_PTH_Through.DRL, Drill_PTH_Through_Via.DRL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]
2024-11-29 Fix some of these crappy traces
    [Drill_NPTH_Through.DRL, Drill_PTH_Through.DRL, Drill_PTH_Through_Via.DRL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]
